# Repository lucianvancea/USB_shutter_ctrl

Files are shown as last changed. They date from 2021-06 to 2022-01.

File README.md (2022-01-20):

# Hardware shutter control for astrophotography 

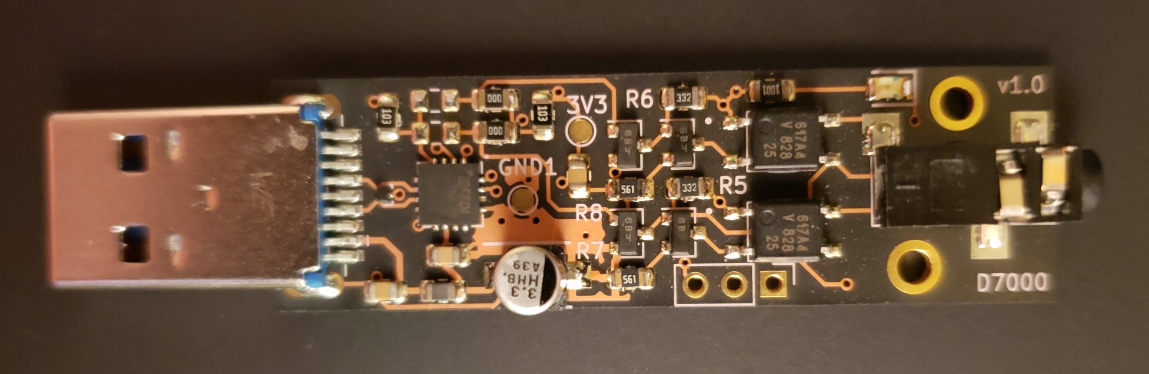
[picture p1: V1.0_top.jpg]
Top


## Intro
* Done in KiCad 
* Tested with [NINA]( https://nighttime-imaging.eu/ ) and Nikon D7000
* Works with this cable [ZWO ASIAIR N3]( https://astronomy-imaging-camera.com/product/zwo-shutter-release-cable-for-asiair-pro )
* [Video of board being soldered]( https://www.youtube.com/watch?v=h37NhTkAf3A&t)
* Uses RTS signal from an USB to UART bridge to control shutter release (and exposure time)

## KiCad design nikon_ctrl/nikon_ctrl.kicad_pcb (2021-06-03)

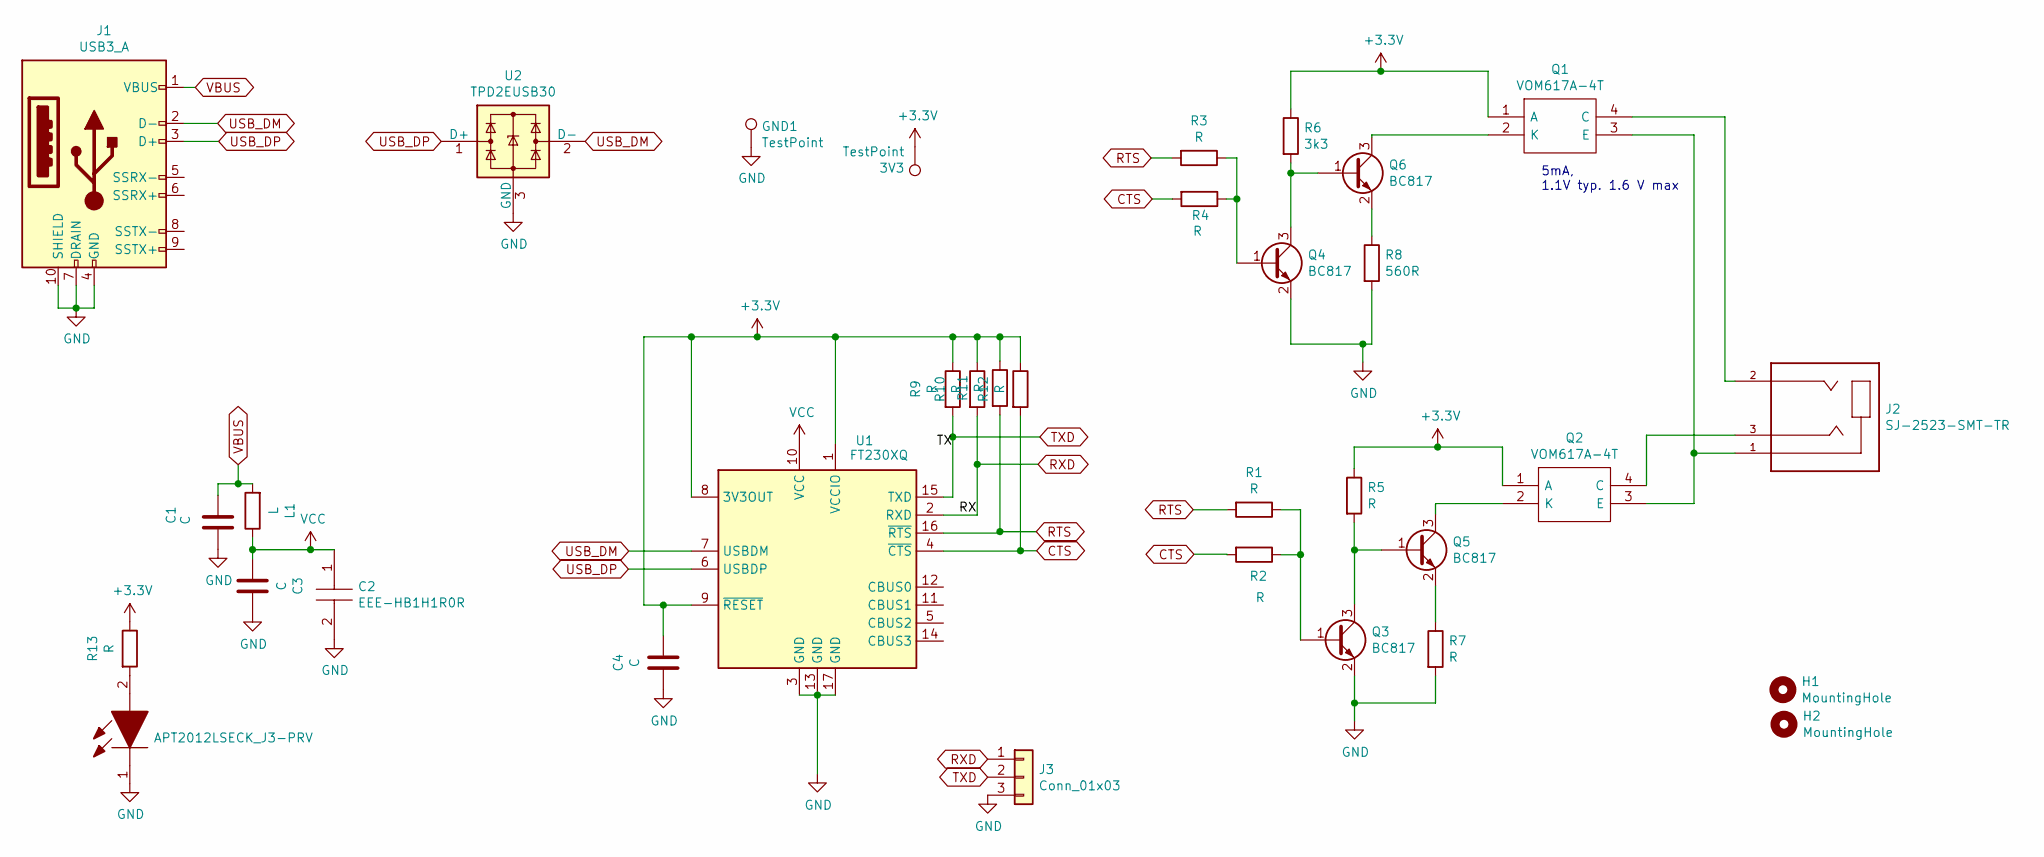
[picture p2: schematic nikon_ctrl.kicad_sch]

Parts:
3V3: TestPoint; TestPoint_Pad_D1.5mm
C1, C3, C4: C; C_0805_2012Metric
C2: EEE-HB1H1R0R; CAPAE430X610N; Mouser Part Number 667-EEE-HB1H1R0R
GND1: TestPoint; TestPoint_Pad_D1.5mm
H1, H2: MountingHole; MountingHole_2.2mm_M2_ISO7380_Pad
J1: USB3_A; USB3_A_Plug_Wuerth_692112030100_Horizontal
J2: SJ-2523-SMT-TR; CUI_SJ-2523-SMT-TR
J3: Conn_01x03; PinHeader_1x03_P2.54mm_Vertical
L1: L; R_0805_2012Metric_Pad1.15x1.40mm_HandSolder
LED1: APT2012LSECK_J3-PRV; LEDC2012X75N; Mouser Part Number 604-APT2012LSECKJ3RV
Q1, Q2: VOM617A-4T; VOM617A8X001T; Mouser Part Number 78-VOM617A-4T
Q3, Q4, Q5, Q6: BC817; SOT-23
R1, R2, R3, R4, R5, R7, R9, R10, R11, R12, R13: R; R_0805_2012Metric_Pad1.15x1.40mm_HandSolder
R6: 3k3; R_0805_2012Metric_Pad1.15x1.40mm_HandSolder
R8: 560R; R_0805_2012Metric_Pad1.15x1.40mm_HandSolder
U1: FT230XQ; QFN-16-1EP_4x4mm_P0.65mm_EP2.1x2.1mm
U2: TPD2EUSB30; Texas_DRT-3

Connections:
+3V3: 3V3.1, C4.2, Q1.1 (A), Q2.1 (A), R5.1, R6.1, R9.1, R10.1, R11.1, R12.1, R13.1, U1.1 (VCCIO), U1.8 (3V3OUT), U1.9 (~RESET)
CTS: R2.2, R4.2, R12.2, U1.4 (~CTS)
GND: C1.2, C2.2, C3.2, C4.1, GND1.1, J1.4 (GND), J1.7 (DRAIN), J1.10 (SHIELD), J3.3, LED1.1, Q3.2 (E), Q4.2 (E), R7.2, R8.2, U1.3 (GND), U1.13 (GND), U1.17 (GND), U2.3 (GND)
unnamed: J2.1, Q1.3 (E), Q2.3 (E)
unnamed: J2.2, Q1.4 (C)
unnamed: J2.3, Q2.4 (C)
unnamed: LED1.2, R13.2
unnamed: Q1.2 (K), Q6.3 (C)
unnamed: Q2.2 (K), Q5.3 (C)
unnamed: Q3.1 (B), R1.1, R2.1
unnamed: Q3.3 (C), Q5.1 (B), R5.2
unnamed: Q4.1 (B), R3.1, R4.1
unnamed: Q4.3 (C), Q6.1 (B), R6.2
unnamed: Q5.2 (E), R7.1
unnamed: Q6.2 (E), R8.1
RTS: R1.2, R3.2, R11.2, U1.16 (~RTS)
RXD: J3.1, R10.2, U1.2 (RXD)
TXD: J3.2, R9.2, U1.15 (TXD)
USB_DM: J1.2 (D-), U1.7 (USBDM), U2.2 (D-)
USB_DP: J1.3 (D+), U1.6 (USBDP), U2.1 (D+)
VBUS: C1.1, J1.1 (VBUS), L1.2
VCC: C2.1, C3.1, L1.1, U1.10 (VCC)

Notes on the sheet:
5mA, 1.1V typ. 1.6 V max

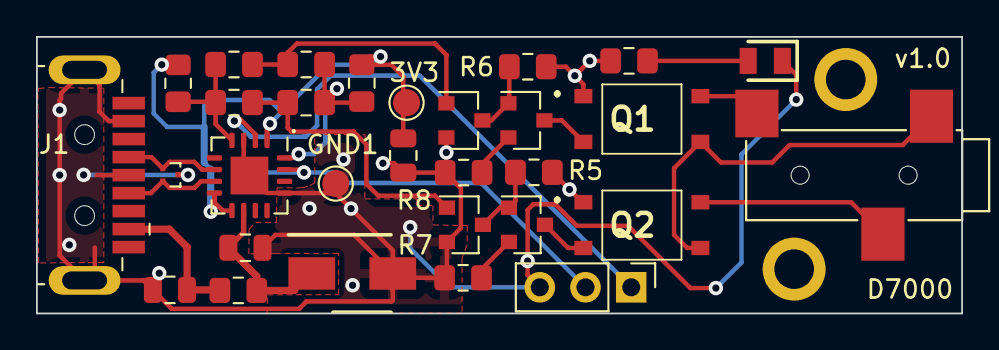
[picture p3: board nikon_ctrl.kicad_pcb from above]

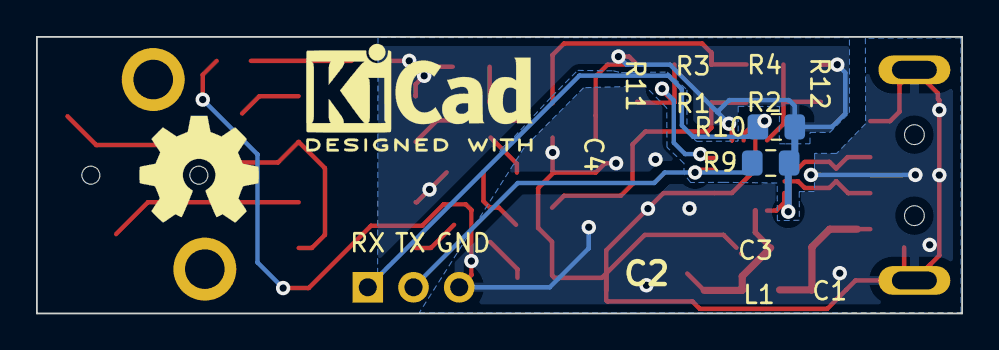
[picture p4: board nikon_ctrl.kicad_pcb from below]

Board: 2 copper layers, 51.4 x 15.4 mm, 34 parts (2 on the bottom side), 22 nets.

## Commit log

2021-06-03 adding output for V1.0
    [nikon_ctrl-B_Cu.gbl, nikon_ctrl-B_Mask.gbs, nikon_ctrl-B_Paste.gbp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]
2021-06-03 adding kicad files
    [nikon_ctrl.kicad_pcb, nikon_ctrl.kicad_sch]
2021-06-12 updated component values
    [nikon_ctrl.kicad_sch]
